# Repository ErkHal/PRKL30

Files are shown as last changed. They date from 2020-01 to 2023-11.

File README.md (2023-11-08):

# PRKL30



## About
30% Custom mechanical keyboard designed  
for the Finnish Mechanical Keyboard Community

Designed by:  
- Ergorius (AKA [ErkHal](https://github.com/ErkHal))
- Tooni Skyy ([TooniSkyy on Github](https://github.com/TooniSkyy))
- Migiii
- Ortho-leaning

## Specs

- 30%, ultra-portable layout
- Powered by QMK Firmware -> [QMK repo folder](https://github.com/qmk/qmk_firmware/tree/master/keyboards/handwired/prkl30)
- Cherry MX, Alps and Choc switch support
- Works with a Pro Micro or Adafruit Feather for bluetooth
- Supports one rotary encoder

## Making it yourself

## PCB
"gerber" folder has the files needed for PCB orders, you can just send the ZIP file to the manufacturer of your choice.  

## Case & Plate
"KLE" folder has layout files that you can use to order plates and make KLE layout pictures for keymap readmes.  
You can use the kle_raw.txt data to create plate files with [ai03 plate generator](https://kbplate.ai03.me/) or [swillkb plate generator](http://builder.swillkb.com/)

There are a few different acrylic case designs [in this repo](https://github.com/TooniSkyy/prkl30-case)

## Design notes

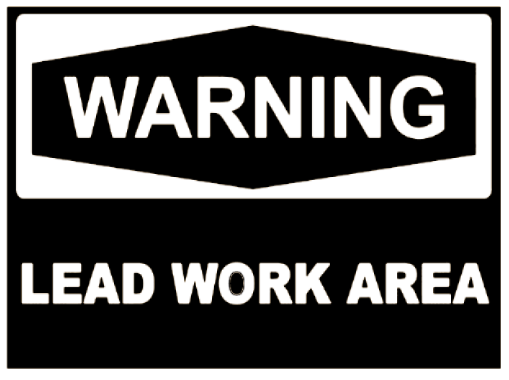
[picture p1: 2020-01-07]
png/LEAD WARNING_2.png

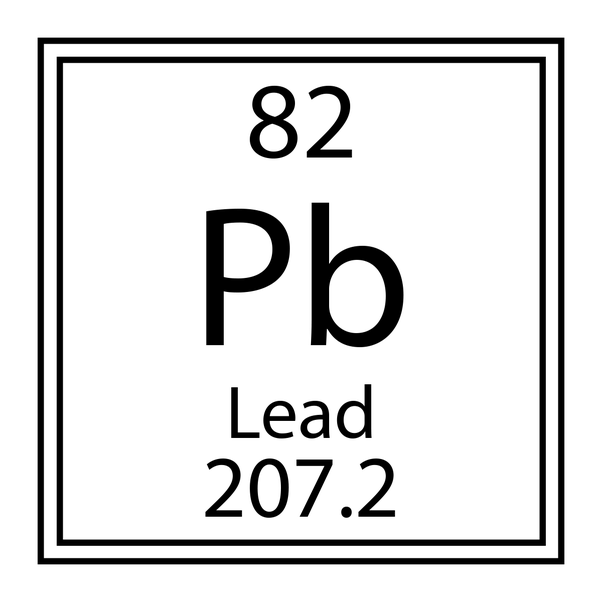
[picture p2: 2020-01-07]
png/Pb.png

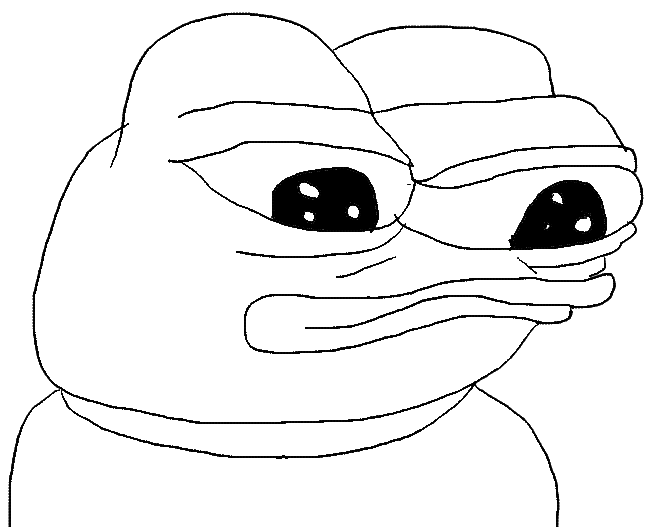
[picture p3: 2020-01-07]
png/Pepe_2.png

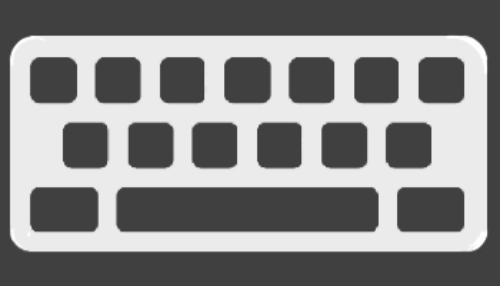
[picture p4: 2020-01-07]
png/prklplain2.png

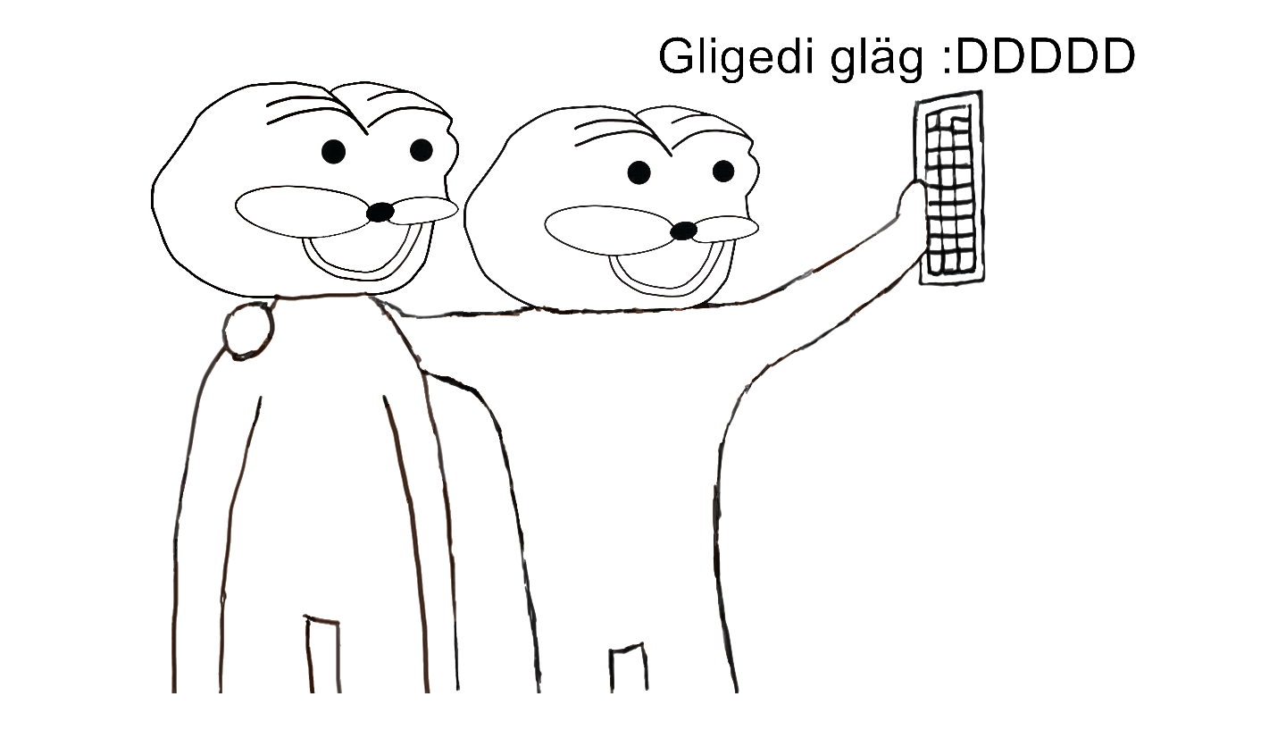
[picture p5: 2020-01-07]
png/Gligediglag.png

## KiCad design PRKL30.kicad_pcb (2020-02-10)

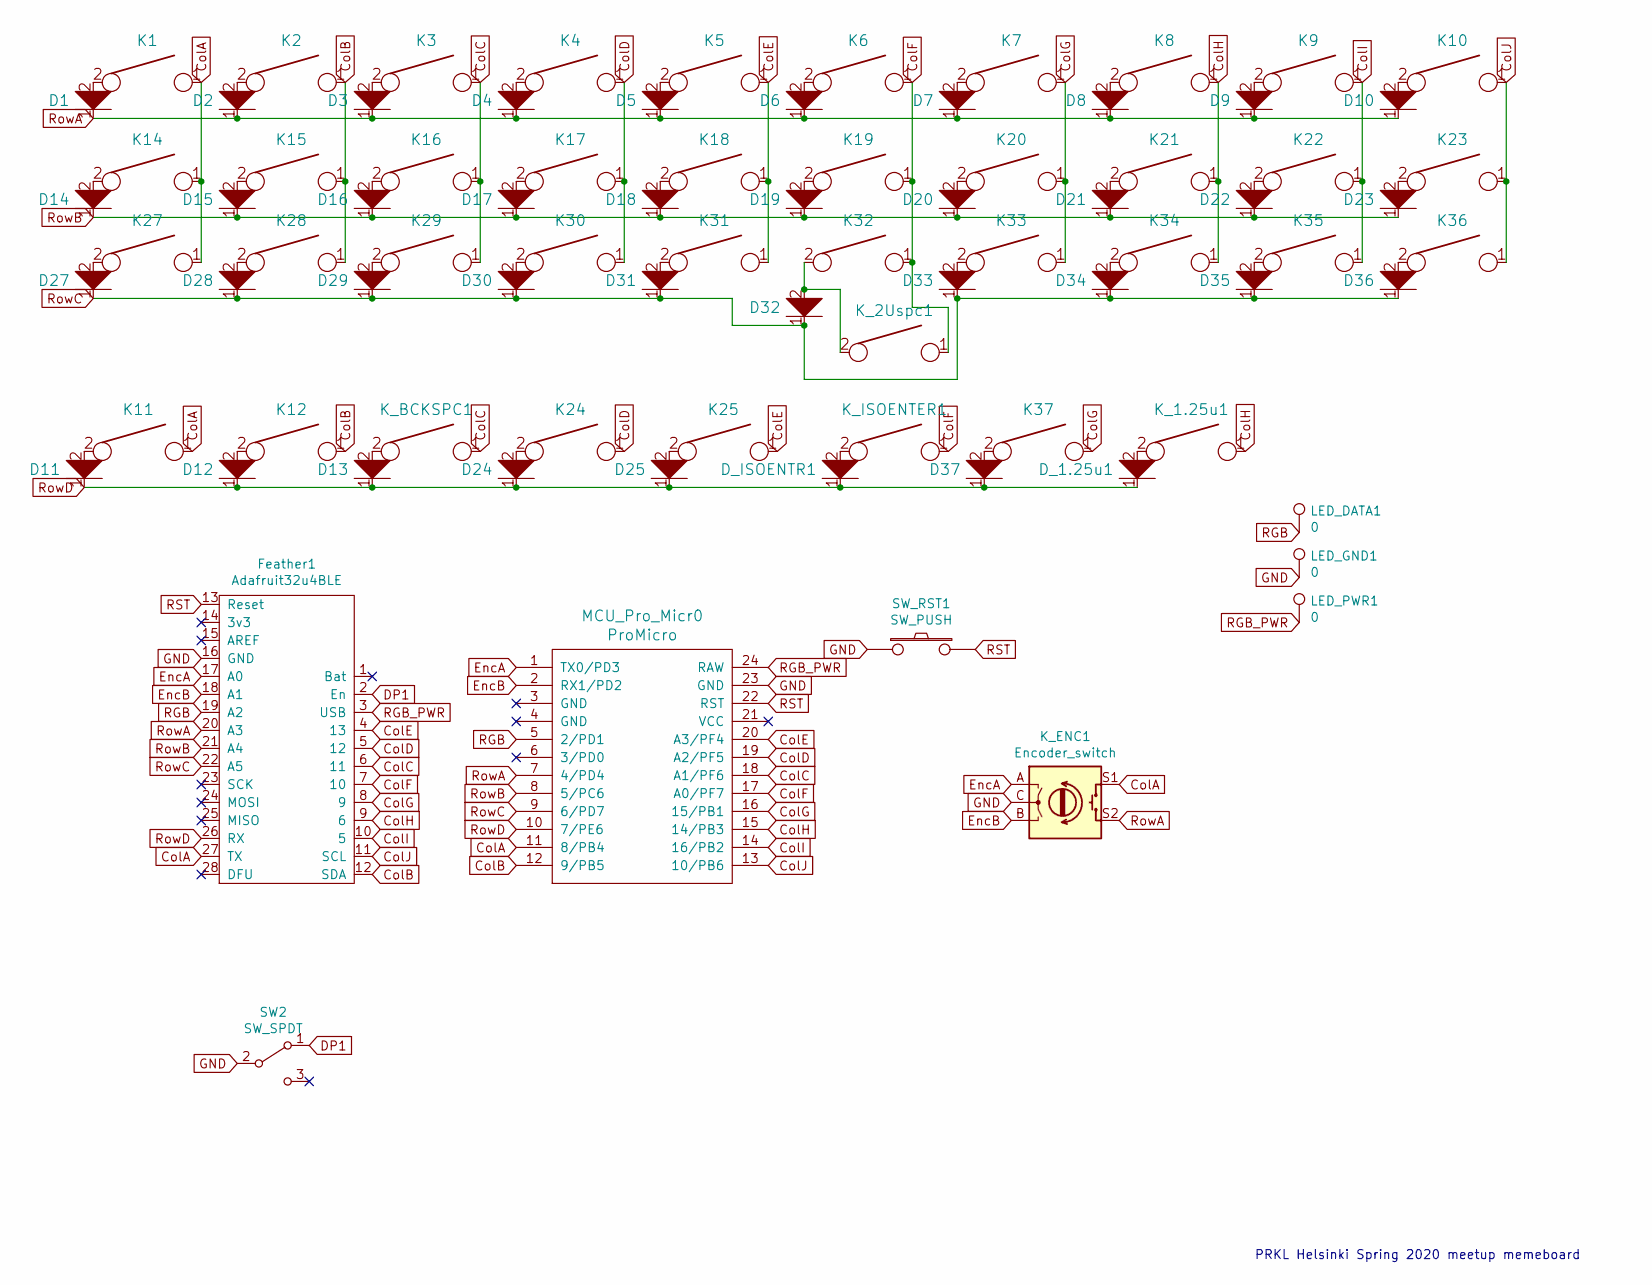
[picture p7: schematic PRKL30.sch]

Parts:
D1, D2, D3, D4, D5, D6, D7, D8, D9, D10, D11, D12, D13, D14, D15, D16, D17, D18, D19, D20, D21, D22, D23, D24, D25, D27, D28, D29, D30, D31, D32, D33, D34, D35, D36, D37: D; D_SOD123_axial
D_1.25u1: D; D_SOD123_axial
D_ISOENTR1: D; D_SOD123_axial
Feather1: Adafruit32u4BLE
K1, K2, K3, K4, K5, K6, K7, K8, K9, K10, K11, K12, K14, K15, K16, K17, K18, K19, K20, K21, K22, K23, K24, K25, K27, K28, K29, K30, K31, K32, K33, K34, K35, K36, K37: KEYSW; MX-Alps-Choc-1U-NoLED
K_1.25u1: KEYSW; MX-Alps-Choc-1U-NoLED
K_2Uspc1: KEYSW; MX-Alps-Choc-2U
K_BCKSPC1: KEYSW; MX-Alps-Choc-1U-NoLED
K_ENC1: Encoder_switch; RotaryEncoder_Alps_EC11E-Switch_Vertical_H20mm
K_ISOENTER1: KEYSW; MX-Alps-Choc-2U
LED_DATA1: 0; SinglePad
LED_GND1: 0; SinglePad
LED_PWR1: 0; SinglePad
MCU_Pro_Micr0: ProMicro; ArduinoProMicro-BackSide
SW2: SW_SPDT; SW_SPDT_PCM12
SW_RST1: SW_PUSH; SW_SPST_TL3342

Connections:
ColA: Feather1.27 (TX), K1.1, K11.1, K14.1, K27.1, K_ENC1.S1, MCU_Pro_Micr0.11 (8/PB4)
ColB: Feather1.12 (SDA), K2.1, K12.1, K15.1, K28.1, MCU_Pro_Micr0.12 (9/PB5)
ColC: Feather1.6 (11), K3.1, K16.1, K29.1, K_BCKSPC1.1, MCU_Pro_Micr0.18 (A1/PF6)
ColD: Feather1.5 (12), K4.1, K17.1, K24.1, K30.1, MCU_Pro_Micr0.19 (A2/PF5)
ColE: Feather1.4 (13), K5.1, K18.1, K25.1, K31.1, MCU_Pro_Micr0.20 (A3/PF4)
ColF: Feather1.7 (10), K6.1, K19.1, K32.1, K_2Uspc1.1, K_ISOENTER1.1, MCU_Pro_Micr0.17 (A0/PF7)
ColG: Feather1.8 (9), K7.1, K20.1, K33.1, K37.1, MCU_Pro_Micr0.16 (15/PB1)
ColH: Feather1.9 (6), K8.1, K21.1, K34.1, K_1.25u1.1, MCU_Pro_Micr0.15 (14/PB3)
ColI: Feather1.10 (5), K9.1, K22.1, K35.1, MCU_Pro_Micr0.14 (16/PB2)
ColJ: Feather1.11 (SCL), K10.1, K23.1, K36.1, MCU_Pro_Micr0.13 (10/PB6)
DP1: Feather1.2 (En), SW2.1 (A)
EncA: Feather1.17 (A0), K_ENC1.A, MCU_Pro_Micr0.1 (TX0/PD3)
EncB: Feather1.18 (A1), K_ENC1.B, MCU_Pro_Micr0.2 (RX1/PD2)
GND: Feather1.16 (GND), K_ENC1.C, LED_GND1.1, MCU_Pro_Micr0.23 (GND), SW2.2 (B), SW_RST1.1
unnamed: D1.2, K1.2
unnamed: D2.2, K2.2
unnamed: D3.2, K3.2
unnamed: D4.2, K4.2
unnamed: D5.2, K5.2
unnamed: D6.2, K6.2
unnamed: D7.2, K7.2
unnamed: D8.2, K8.2
unnamed: D9.2, K9.2
unnamed: D10.2, K10.2
unnamed: D11.2, K11.2
unnamed: D12.2, K12.2
unnamed: D13.2, K_BCKSPC1.2
unnamed: D14.2, K14.2
unnamed: D15.2, K15.2
unnamed: D16.2, K16.2
unnamed: D17.2, K17.2
unnamed: D18.2, K18.2
unnamed: D19.2, K19.2
unnamed: D20.2, K20.2
unnamed: D21.2, K21.2
unnamed: D22.2, K22.2
unnamed: D23.2, K23.2
unnamed: D24.2, K24.2
unnamed: D25.2, K25.2
unnamed: D27.2, K27.2
unnamed: D28.2, K28.2
unnamed: D29.2, K29.2
unnamed: D30.2, K30.2
unnamed: D31.2, K31.2
unnamed: D32.2, K32.2, K_2Uspc1.2
unnamed: D33.2, K33.2
unnamed: D34.2, K34.2
unnamed: D35.2, K35.2
unnamed: D36.2, K36.2
unnamed: D37.2, K37.2
unnamed: D_1.25u1.2, K_1.25u1.2
unnamed: D_ISOENTR1.2, K_ISOENTER1.2
RGB: Feather1.19 (A2), LED_DATA1.1, MCU_Pro_Micr0.5 (2/PD1)
RGB_PWR: Feather1.3 (USB), LED_PWR1.1, MCU_Pro_Micr0.24 (RAW)
RST: Feather1.13 (Reset), MCU_Pro_Micr0.22 (RST), SW_RST1.2
RowA: D1.1, D2.1, D3.1, D4.1, D5.1, D6.1, D7.1, D8.1, D9.1, D10.1, Feather1.20 (A3), K_ENC1.S2, MCU_Pro_Micr0.7 (4/PD4)
RowB: D14.1, D15.1, D16.1, D17.1, D18.1, D19.1, D20.1, D21.1, D22.1, D23.1, Feather1.21 (A4), MCU_Pro_Micr0.8 (5/PC6)
RowC: D27.1, D28.1, D29.1, D30.1, D31.1, D32.1, D33.1, D34.1, D35.1, D36.1, Feather1.22 (A5), MCU_Pro_Micr0.9 (6/PD7)
RowD: D11.1, D12.1, D13.1, D24.1, D25.1, D37.1, D_1.25u1.1, D_ISOENTR1.1, Feather1.26 (RX), MCU_Pro_Micr0.10 (7/PE6)

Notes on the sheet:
PRKL Helsinki Spring 2020 meetup memeboard

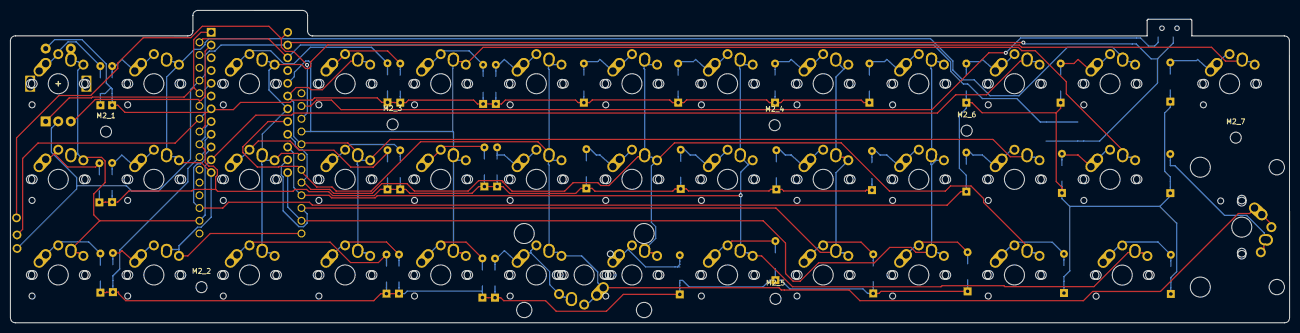
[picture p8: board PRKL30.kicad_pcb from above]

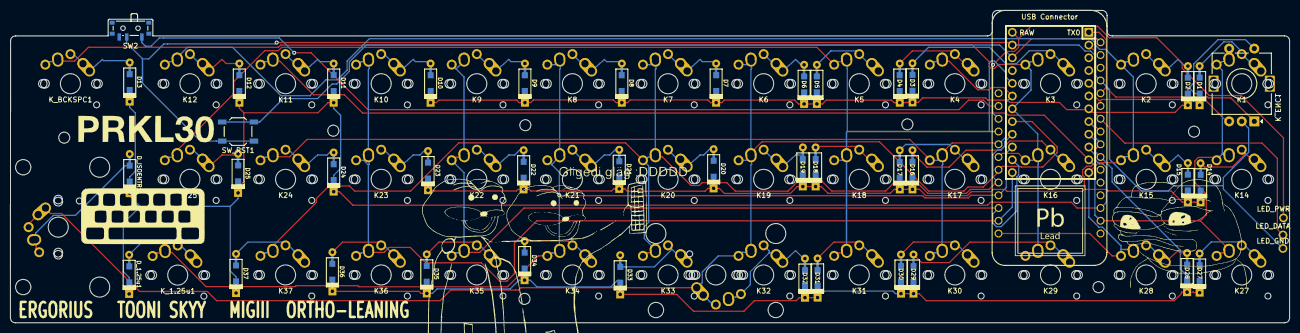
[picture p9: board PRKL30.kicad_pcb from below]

Board: 2 copper layers, 254.9 x 62.2 mm, 94 parts (45 on the bottom side), 59 nets.

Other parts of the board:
G_PB: LOGO_PB; Pb
G_silk_gfx: LOGO_GFX; PRKL30SILK
M2_1, M2_2, M2_3, M2_4, M2_5, M2_6, M2_7: VAL**; MountingHole_2.2mm_M2

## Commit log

2020-01-04 Add unfinished pcb
    [Memekeeb.kicad_pcb]
2020-01-05 Add WS2812B LED Strip support
    [Memekeeb.kicad_pcb, Memekeeb.sch]
2020-01-05 Move WS2812 pins to the side, rearrange diode footprints
    [Memekeeb.kicad_pcb]
2020-01-07 Add files via upload
    "valmiit kuvat ja silkit" kansiosta löytyy png ja silkit. Jostain syystä en saannut renderissä näkymään silkkejä vaikka ne näkyvät pcb view.
    [PRKL30.kicad_pcb, PRKL30.sch]
2020-01-08 Prototype version
    [Memekeeb-B.Cu.gbl, Memekeeb-B.Mask.gbs, Memekeeb-B.Paste.gbp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]
2020-01-28 Rotate one diode footprint, Add silkscreen text for underglow pins, fix autoroute mistakes
    [PRKL30.kicad_pcb]
2020-01-28 Cleanup old files, generate new gerbers
    [Memekeeb-B.Cu.gbl, Memekeeb-B.Mask.gbs, Memekeeb-B.Paste.gbp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]
2020-01-28 edited and flipped mc positions, edited silks also moved diodes and reset button
2020-01-29 mc's flipped, pro micro moved, silks fixed, reset button and diodes moved
    [PRKL30.kicad_pcb]
2020-01-29 Move bluetooth switch, make room for battery between middle standoffs
    [PRKL30.kicad_pcb]
2020-02-03 Add new routings, change mounting holes to M2
    [PRKL30.kicad_pcb]
2020-02-03 Generated new plot and drill files
    [PRKL30-B.Cu.gbl, PRKL30-B.Mask.gbs, PRKL30-B.Paste.gbp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]
2020-02-10 moved ble switch and edited pcb outlines and traces related to that
    [PRKL30.kicad_pcb]
